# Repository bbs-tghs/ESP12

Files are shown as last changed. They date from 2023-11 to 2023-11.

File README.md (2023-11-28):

# ESP12
Ein Übungssystem für den Unterricht auf Basis des MikroControllers ESP-12 und der Arduino-Umgebung

Das System besteht aus einer Platine im Format 160x100mm. Es vereint neben dem eigentlichen Controller ESP-E12 einige Taster, ein paar LEDs einen Summer und ein Display sowie ein kleines Steckbrett für eigene Erweiterungen. Alle verfügbaren Portpins sind auf eine Stiftleite herausgeführt. Die Verdrahtung erfolgt Arduino-typisch per Jumperkabel.



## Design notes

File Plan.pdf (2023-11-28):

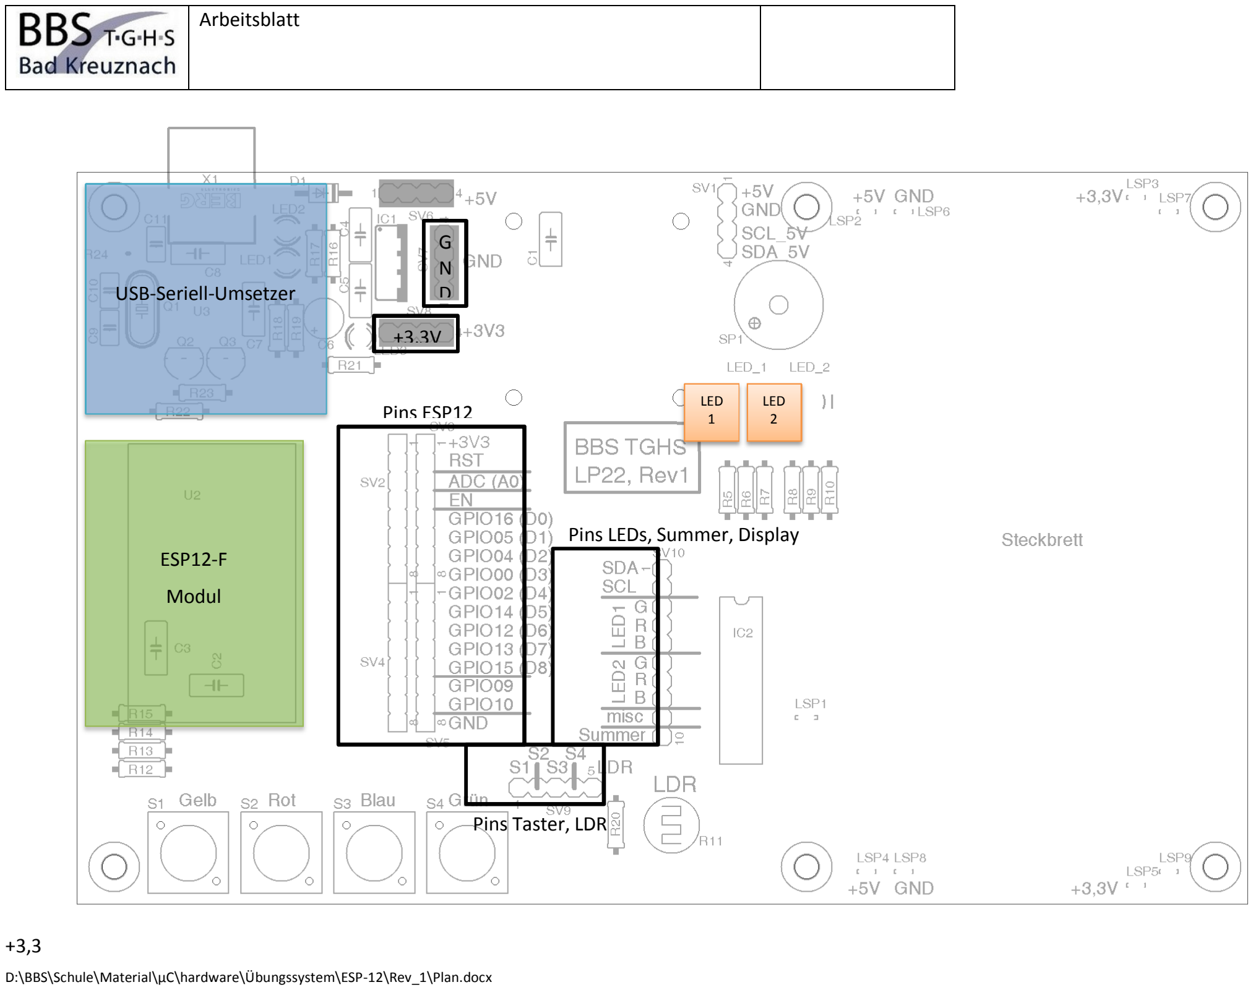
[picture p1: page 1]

Arbeitsblatt

D:\BBS\Schule\Material\µC\hardware\Übungssystem\ESP-12\Rev_1\Plan.docx

+3,3

ESP12-F

Modul

G
N
D

+3,3V

LED
1

LED
2

USB-Seriell-Umsetzer

Pins ESP12

Pins LEDs, Summer, Display

Pins Taster, LDR

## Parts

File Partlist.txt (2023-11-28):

Partlist

Exported from bbstghs_wlan.brd at 21.07.2018 16:31:17

EAGLE Version 5.9.0 Copyright (c) 1988-2010 CadSoft

Part     Value          Package       Library  Position (mil)        Orientation

C1       100n           C050-030X075  bbstghs  (2550 3575)           R90
C2       100nF          C050-030X075  bbstghs  (750 1175)            R180
C3       100nF          C050-030X075  bbstghs  (425 1375)            R270
C4       100n           C050-030X075  bbstghs  (1525 3600)           R270
C5       100n           C050-030X075  bbstghs  (1525 3300)           R90
C6       10µ            E2,5-6        bbstghs  (1325 3150)           R90
C7       100n           C050-030X075  bbstghs  (950 3200)            R90
C8       100n           C050-030X075  bbstghs  (650 3500)            R180
C9       22p            C025-025X050  bbstghs  (175 3100)            R270
C10      22p            C025-025X050  bbstghs  (175 3300)            R90
C11      10n            C025-025X050  bbstghs  (425 3550)            R90
D1       1N581          DO41-10       bbstghs  (1325 3825)           R180
IC1      LV33CV         78XXS         v-reg-3  (1775 3450)           R270
IC2      ULN2803A       DIL18         uln-udn  (3575 1200)           R270
LED1                    LED3MM        bbstghs  (1125 3450)           R180
LED2                    LED3MM        bbstghs  (1125 3625)           R180
LED3                    LED3MM        bbstghs  (1525 3050)           R270
LED_1    RGBLED         RGBLED        bbstghs  (3600 2700)           R90
LED_2    RGBLED         RGBLED        bbstghs  (3950 2700)           R90
LSP1     LSP13          LSP13         solpad   (3925 1000)           R0
LSP2     LSP10          LSP10         solpad   (4250 3725)           R0
LSP3     LSP10          LSP10         solpad   (5700 3800)           R0
LSP4     LSP10          LSP10         solpad   (4250 175)            R0
LSP5     LSP10          LSP10         solpad   (5700 100)            R0
LSP6     LSP10          LSP10         solpad   (4450 3725)           R0
LSP7     LSP10          LSP10         solpad   (5875 3725)           R0
LSP8     LSP10          LSP10         solpad   (4450 175)            R0
LSP9     LSP10          LSP10         solpad   (5875 175)            R0
Q1       12MHz          HC49/S        bbstghs  (350 3200)            R270
Q2       BC337          TO92          bbstghs  (575 2925)            R180
Q3       BC337          TO92          bbstghs  (800 2925)            R180
R1       10k            R1206         bbstghs  (3200 3350)           MR270
R2       4k7            R1206         bbstghs  (2900 3350)           MR270
R3       10k            R1206         bbstghs  (2725 3175)           MR180
R4       4k7            R1206         bbstghs  (2900 3025)           MR90
R5       470R           0207/10       bbstghs  (3500 2225)           R90
R6       470R           0207/10       bbstghs  (3600 2225)           R90
R7       470R           0207/10       bbstghs  (3700 2225)           R90
R8       470R           0207/10       bbstghs  (3850 2225)           R90
R9       470R           0207/10       bbstghs  (3950 2225)           R90
R10      470R           0207/10       bbstghs  (4050 2225)           R90
R11      LDRLDR         LDR           bbstghs  (3200 425)            R270
R12      10k            0207/10       bbstghs  (350 725)             R180
R13      10k            0207/10       bbstghs  (350 825)             R180
R14      10k            0207/10       bbstghs  (350 925)             R180
R15      10k            0207/10       bbstghs  (350 1025)            R180
R16      1k             0207/10       bbstghs  (1375 3500)           R270
R17      1k             0207/10       bbstghs  (1275 3500)           R270
R18      470R           0207/10       bbstghs  (1075 3100)           R270
R19      470R           0207/10       bbstghs  (1175 3100)           R270
R20      470R           0207/10       bbstghs  (2900 425)            R90
R21      1k             0207/10       bbstghs  (1475 2900)           R0
R22      12k            0207/10       bbstghs  (550 2650)            R180
R23      12k            0207/10       bbstghs  (675 2750)            R0
R24      1M             0204V         bbstghs  (275 3500)            R180
S1       MTG_1241       SCHURTER_MTG  bbstghs  (450 125)             R0
S2       MTG_1241       SCHURTER_MTG  bbstghs  (950 125)             R0
S3       MTG_1241       SCHURTER_MTG  bbstghs  (1450 125)            R0
S4       MTG_1241       SCHURTER_MTG  bbstghs  (1950 125)            R0
SJ1                     SJW           jumper   (1350 2700)           MR0
SJ2                     SJW           jumper   (1350 2500)           MR0
SP1      AC-1205G       KSS1201       bbstghs  (3775 3225)           R180
SV1                     MA04-1        con-lstb (3500 3675)           R270
SV2                     FE08          con-lsta (1725 2125)           R270
SV3                     FE08          con-lsta (1875 2125)           R270
SV4                     FE08          con-lsta (1725 1325)           R270
SV5                     FE08          con-lsta (1875 1325)           R270
SV6                     MA04-1        con-lstb (1825 3825)           R0
SV7                     MA04-1        con-lstb (1975 3450)           R90
SV8                     MA04-1        con-lstb (1825 3075)           R0
SV9                     MA05-1        con-lstb (2575 625)            R0
SV10                    MA10-1        con-lstb (3150 1350)           R270
T1       BSS138         SOT23         bbstghs  (3050 3350)           MR90
T2       BSS138         SOT23         bbstghs  (2675 3325)           MR180
U1       OLED_096       OLED_096      bbstghs  (2250 2650)           R0
U2       ESP-12F-MODUL  ESP-12F_MODUL bbstghs  (775 1975)            R0
U3       CH340G         SO16          bbstghs  (675 3200)            R180
X1       PN61729-S      PN61729-S     bbstghs  (725 3775)            R180

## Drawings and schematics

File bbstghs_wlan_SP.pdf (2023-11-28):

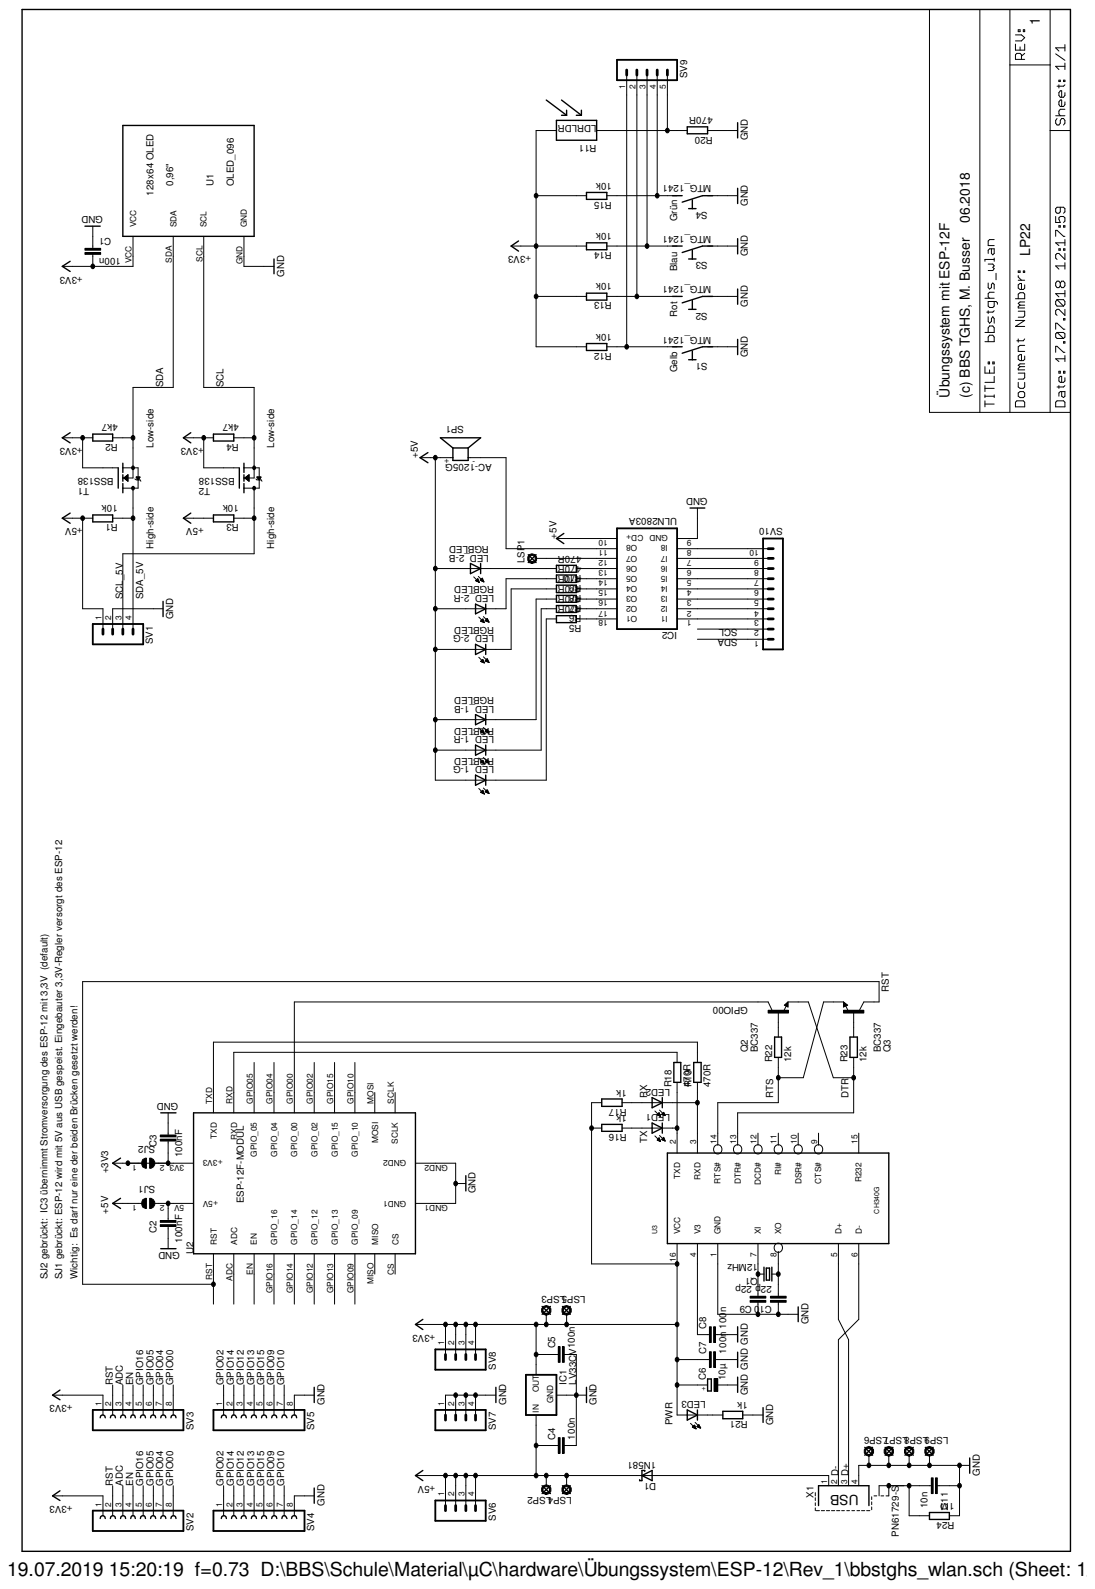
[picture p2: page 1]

Gelb Rot Blau Grün

High-side Low-side

SJ1 gebrückt: ESP-12 wird mit 5V aus USB gespeist. Eingebauter 3,3V-Regler versorgt des ESP-12

SJ2 gebrückt: IC3 übernimmt Stromversorgung des ESP-12 mit 3,3V (default)

Wichtig: Es darf nur eine der beiden Brücken gesetzt werden!

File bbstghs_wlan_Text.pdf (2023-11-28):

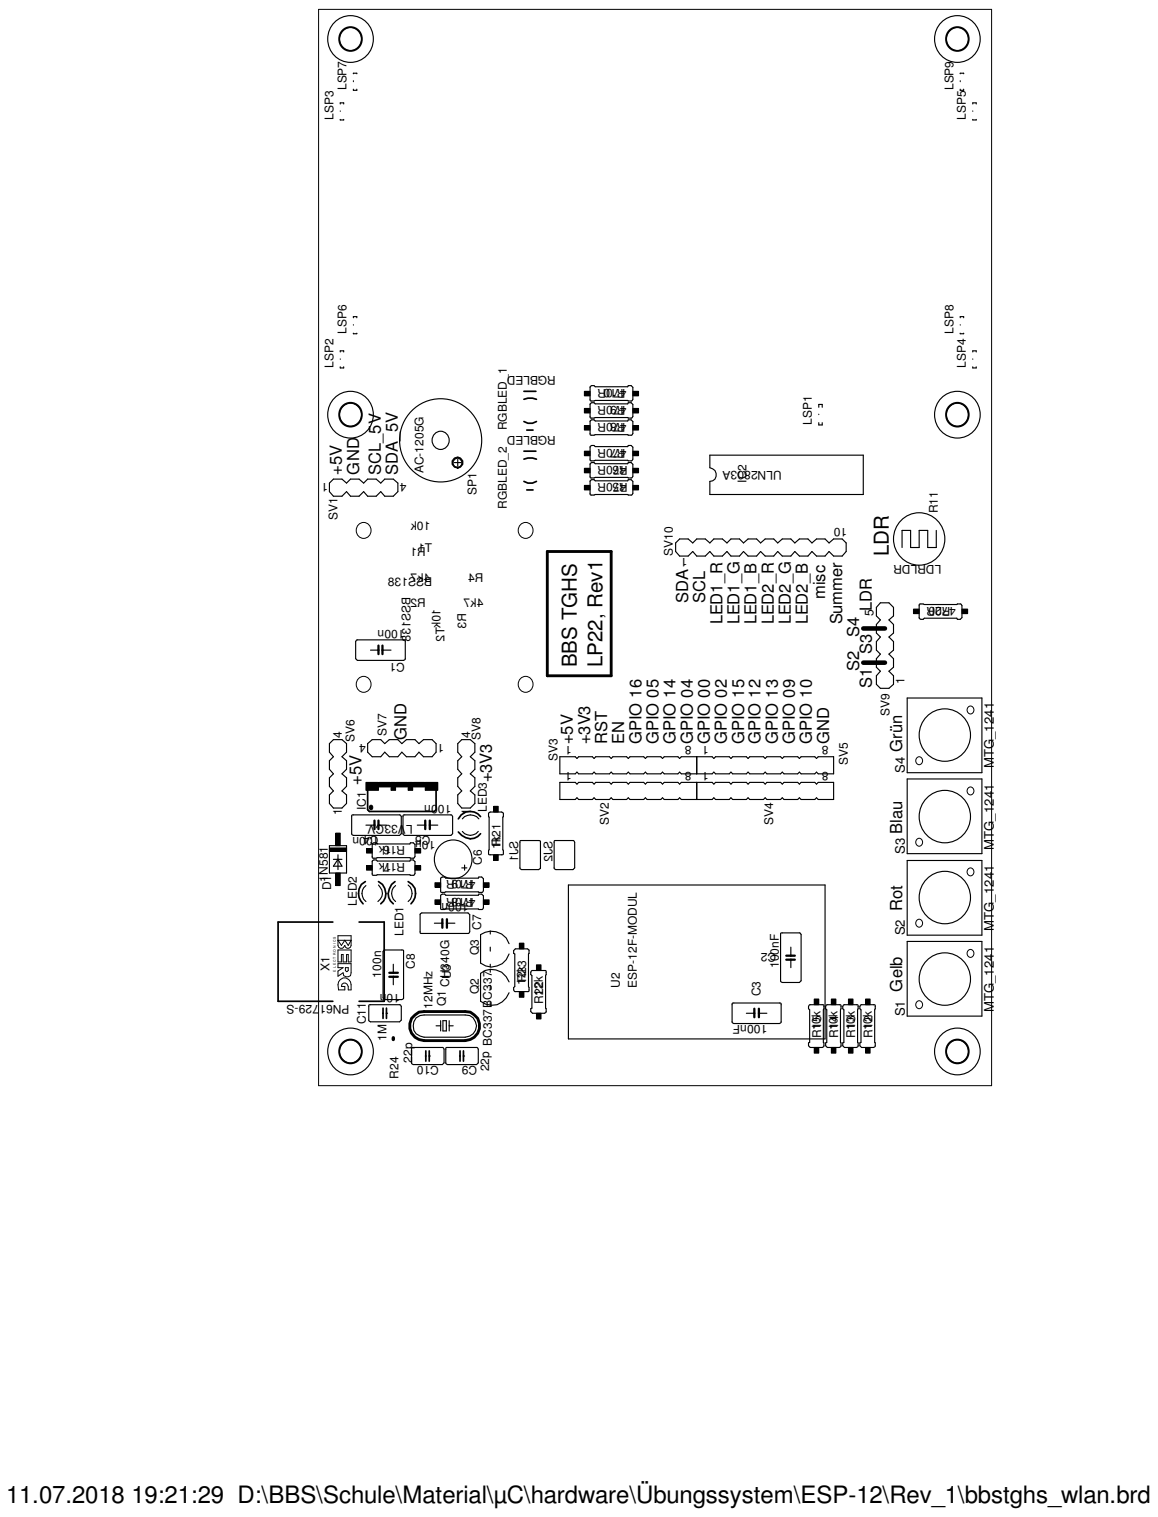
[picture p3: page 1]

Gelb Rot Blau Grün

11.07.2018 19:21:29 D:\BBS\Schule\Material\µC\hardware\Übungssystem\ESP-12\Rev_1\bbstghs_wlan.brd

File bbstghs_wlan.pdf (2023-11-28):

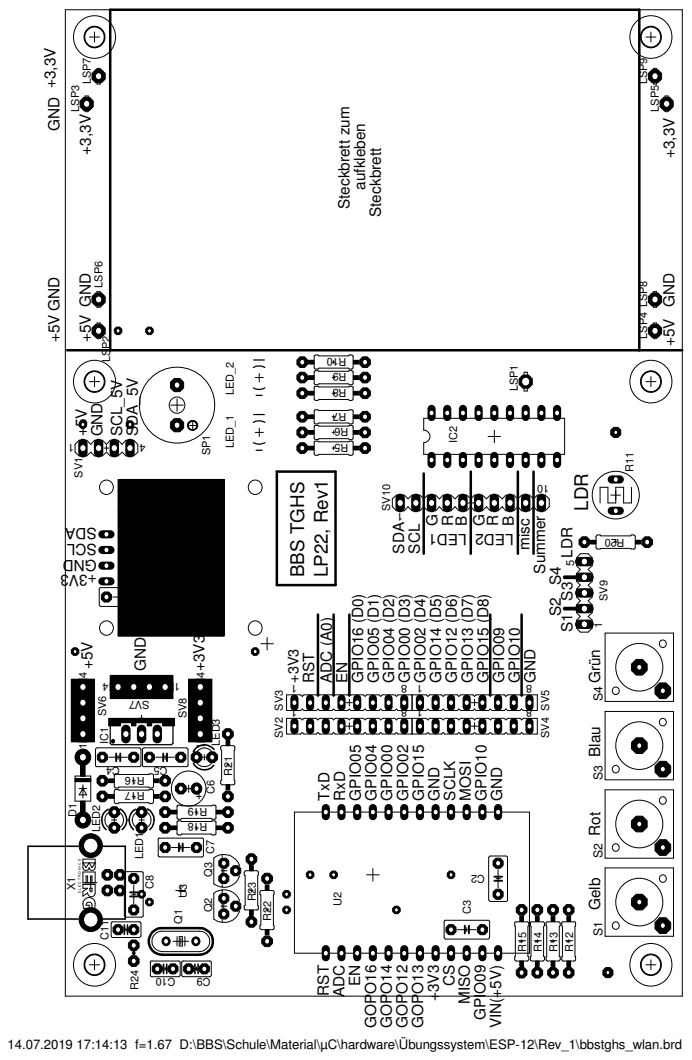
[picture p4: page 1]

Gelb Rot Blau Grün

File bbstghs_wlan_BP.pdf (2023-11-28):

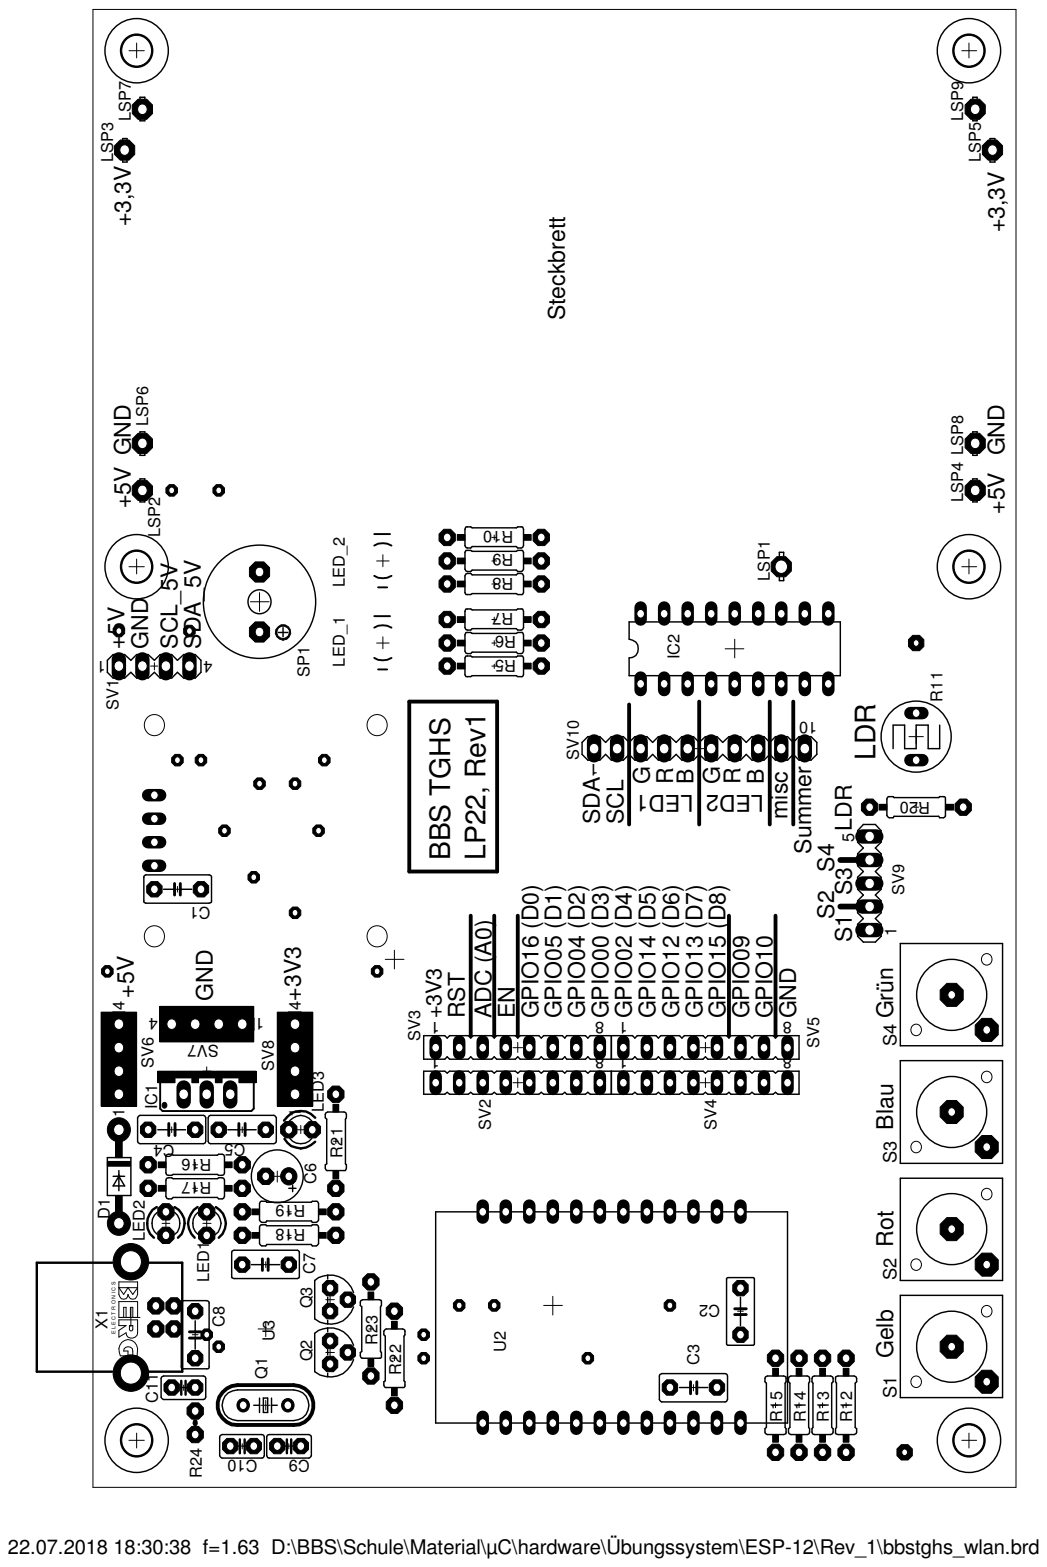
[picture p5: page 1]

Gelb Rot Blau Grün
